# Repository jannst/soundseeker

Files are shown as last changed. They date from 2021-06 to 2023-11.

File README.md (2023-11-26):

# Soundseeker
The Soundseeker project originated from my need to measure the speed of sound traveling through wood, a crucial characteristic in selecting wood for musical instrument making. Regrettably, there was no affordable method available, prompting me to embark on building a device capable of measuring this parameter independently. The project commenced in 2017 with the development of the initial prototype. Throughout the process, I gained valuable insights, and I am currently at the third prototype stage, incorporating a custom PCB, surface-mount device (SMD) parts and even a step-up DC-DC converter to drive the piezo acuator.

This Repository contains only the source code for the third prototype.

## Prototype I (2017)
<div style="display: flex">
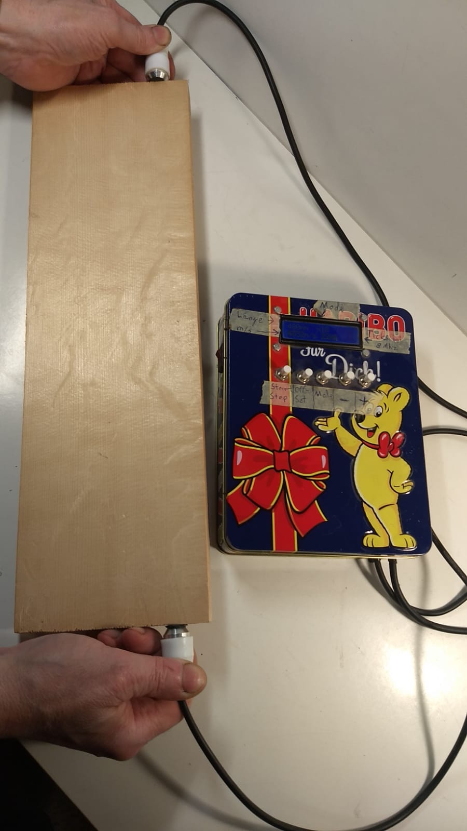
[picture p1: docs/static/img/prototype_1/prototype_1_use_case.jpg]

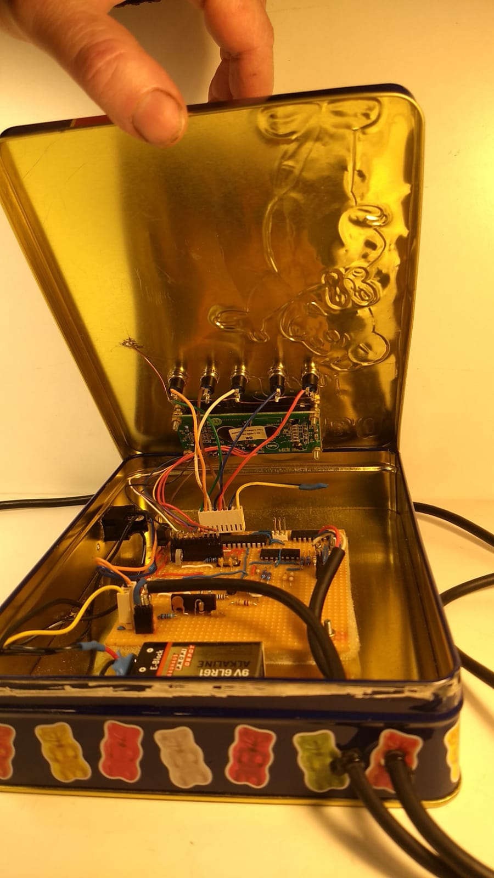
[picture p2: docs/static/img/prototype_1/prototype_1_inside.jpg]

</div>
The first prototype used an ATMEAGA-8 as MCU and a Haribo sweets box as enclosure. 

## Prototype II (2020)
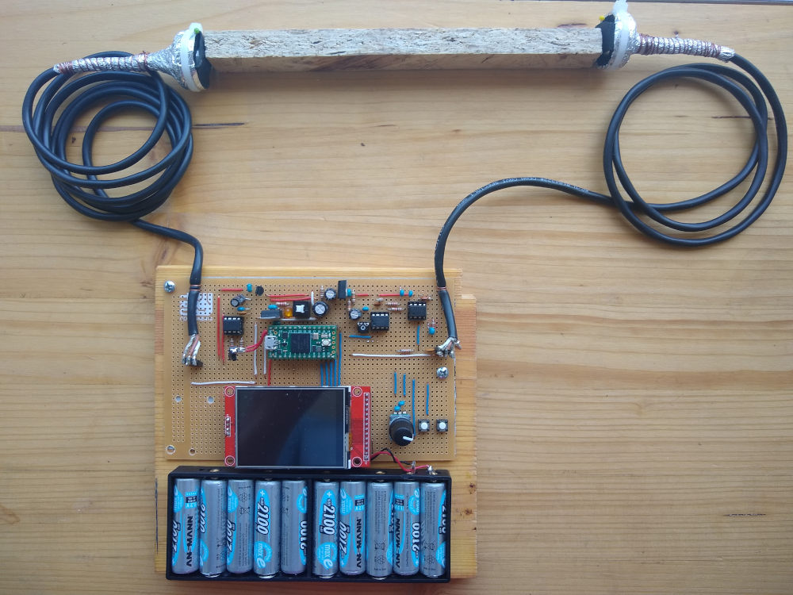
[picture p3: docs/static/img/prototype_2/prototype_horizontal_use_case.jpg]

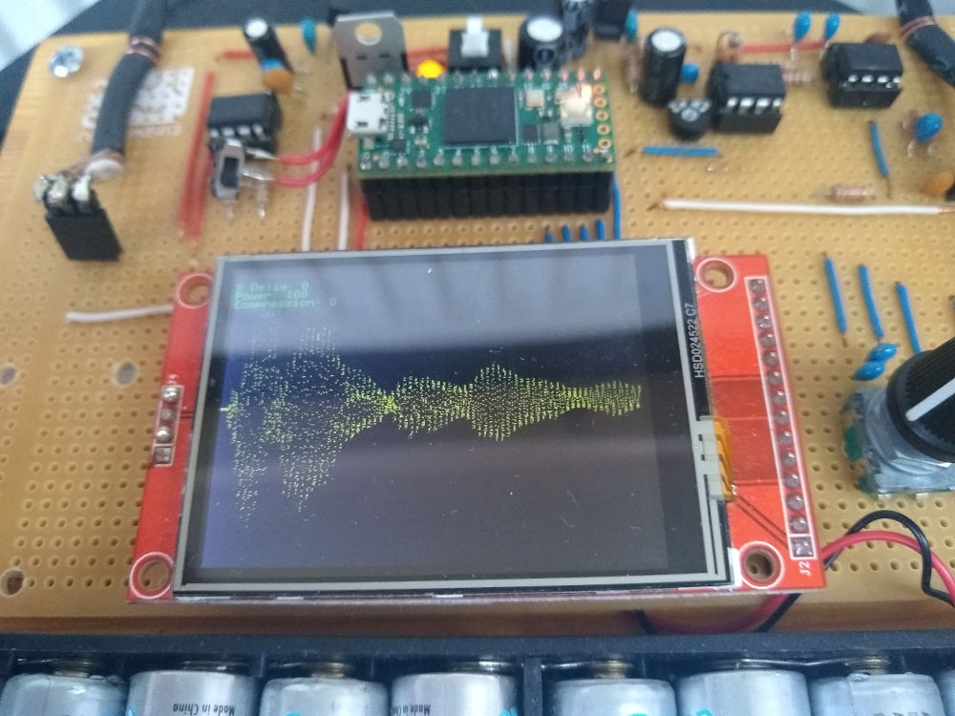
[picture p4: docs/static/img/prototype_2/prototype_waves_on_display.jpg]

The second prototype uses a very powerful Teensy 4 board and utilises a display which even allows to visualise the waveform.

## Prototype III (2022)
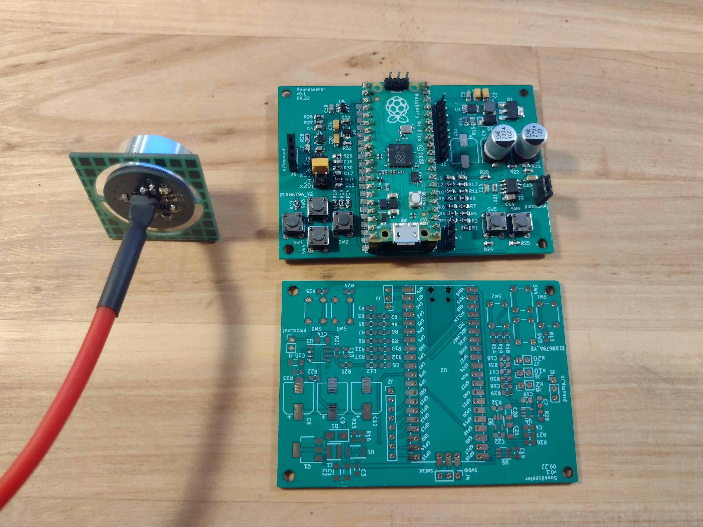
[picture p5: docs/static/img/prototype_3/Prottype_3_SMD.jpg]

The third prototype features custom PCBs and utilizes the RP2040 microcontroller, providing USB connectivity. The display was omitted to enable visualization of transmitted data through laptops or mobile phones connected via USB. The pre-amplifier for the piezo sensor is situated on the PCB to which the sensor is soldered, ensuring a very short, high-impedance signal path.

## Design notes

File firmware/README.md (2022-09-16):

# Soundseeker Firmware

## Project Setup
  - Download RPI Pico SDK and setup `PICO_SDK_PATH` env variable on your system
  - Open Project in VS Code
  - Setup a [picoprobe](https://github.com/raspberrypi/picoprobe) for firmware flashing and debugging
  - Have a look at the scripts inside the bin folder
  - When using serial remember how to leave minicom: CTRL+A, then press X

### Debugging
  Checkout [this Digikey article](https://www.digikey.de/de/maker/projects/raspberry-pi-pico-and-rp2040-cc-part-2-debugging-with-vs-code/470abc7efb07432b82c95f6f67f184c0) on how to debug RP2040 with VS Code

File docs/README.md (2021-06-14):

# Ultrasonic Sound Tester Abstract an logbook site
Uses [Pico](https://github.com/negrel/hugo-theme-pico/) theme

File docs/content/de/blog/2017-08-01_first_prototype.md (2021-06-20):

+++
title = "Der erste Prototyp"
subtitle = ""
date = 2017-08-01

description = "Kurze Beschreibung des ersten Prototypen mit Erläuterung der Arbeitsweise"
banner = ''

[[pic]]
  url = "/img/prototype_1/prototype_1.jpg"
  label = "Gesamtansicht"
  height = "250px"

[[pic]]
  url = "/img/prototype_1/prototype_1_inside.jpg"
  label = "Innenansicht"
  height = "250px"
[[pic]]
  url = "/img/prototype_1/prototype_1_use_case.jpg"
  label = "Messung der Schallgeschwindigkeit in Cello Deckenholz"
  height = "250px"
[[pic]]
  url = "/img/prototype_1/prototype_1_horizontal.jpg"
  label = "Gesamtansicht"
  height = "250px"
+++

Der erste Prototyp ist ein Nachbau, des [Luccimeters](https://www.lucchimeter.com/), welches zur Zeit 
bei F.W. Geigenbu in Bremen im Einsatz ist. Dort  wird es zur Vermessung von Bogen- und Geigenholz genutzt. 

Es verfügt über 2 40kHz Piezo-Elemente, welche den Ultraschall in das Material einbringen und wieder abnehmen. Das Signal wird dann verstärkt und
durch einen Atmega-8 Microcontroller wird ausgewertet, wie lang der Schall benötigt hat um das Material zu durchqueren.
Zusammen mit der eingegebenen Länge wird die Schallgeschwindigkeit im Material gemessen.

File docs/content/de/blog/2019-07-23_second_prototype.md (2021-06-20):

+++
title = "Der zweite Prototyp"
subtitle = ""
date = 2019-07-23

description = "Aufbau und Funktionsweise des zweiten Prototypes"
banner = ''
[[pic]]
  url = "/img/prototype_2/prototype_vertical.jpg"
  label = "Gesamtansicht"
  height = "250px"
[[pic]]
  url = "/img/prototype_2/prototype_backside.jpg"
  label = "Rückseite der Platine"
  height = "250px"
[[pic]]
  url = "/img/prototype_2/prototype_horizontal_use_case.jpg"
  label = "Möglicher Anwendungsfall"
  height = "250px"
[[pic]]
  url = "/img/prototype_2/prototype_waves_on_display.jpg"
  label = "Anzeige der Rohdaten auf dem Display"
  height = "250px"
+++

Der zweite Prototyp arbeitet mit dem selben Piezo-Wandlern, allerdings wurden die Schaltungen für 
die Signalerzeugung und -verstärkung mit Hile von Thomas XXXX, einem pensionierten Elektrotechnisker überarbeitet. 
Es wurde ebenfalls ein Bildschirm und ein leistungsstarker Teensy 4.0 Microcontroller verbaut.
Da dieser über einen 1MSP/S ADC verfügt, können die 40kHz Schallwellen nun abgenommen und digital verarbeitet werden.

Der Prototyp ist in der Lage Schallwellen von 40kHz zu erzeugen, in das Material einzubringen, dann wieder abzunehmen, analog zu verstärken und anschließend auf einem kleinen Display anzuzeigen.

Es fehlt aber noch ein vernünftiges Bewertungsverfahren, welches die abegommenen Schallwellen auswertet. Dabei muss berücksichtigt werden, dass die die Piezos mit der Hand an das Werkstück gehalten werden und die Ergebnisse somit je nach Anpressdruck und -winkel mitunter stark variieren. Gleichzeitig sind die verwendeten Piezos vermutlich nicht die optimale Wahl für die beschriebene Anwendung, es konnten allerdings keine
passenderen Elemente mit dem zur Verfügung stehenden Budget organisiert werden. Es stellt sich außerdem die Frage ob sich 40kHz als Frequenz zur Durschschallung von Feststoffen eignet.
Außerdem muss ein Weg gefunden Werten, einen Piezo Treiber zu betreiben, der möglichst Hohe Spannungsamplitunden liefern, gleichzeitig aber mit einem 5V Akku bereiben werden kann,

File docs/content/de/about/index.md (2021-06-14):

+++
title = "Über das Projekt"

type = "blog"
+++

## Problemstellung
Beim Bau eines Holzmusikinstrumentes muss Holz ausgewählt werden, welches Materialeigenschaften besitzt, die sich positiv auf die akustische Qualität auswirken.
Im Holzhandel müssen somit aus einer Vielzahl von verschiedenen Stücken, einige passende ausgewählt werden.
Um die besten Stücke identifizieren zu können, haben sich über die Jahre verschiedene Heuristiken entwickelt. Relativ bekannt sind verschiedene
"Klopftests", bei denen ein Stück Holz z.B. zwischen zwei Fingern an einem Schwingungsknoten einer Eigenmode gehalten 
und mit der Hand "angeklopft" wird. Der vom Holz abgestrahlte Klang wird dann anhand der eigenen Erfahrung subjektiv bewertet.
Das "geschulte Ohr" ist dann in der Lage, eine Bewertung über die Eignung des Holzes für den Instrumentenbau zu liefern.

Auch bei der Ausarbeitung des Materials ist es wichtig, darauf zu achten, dass später ein akustisch gut klingendes Instrument entsteht. 
So ist bei Gitarren und Streichinstrumenten die Ausarbeitung der Materialstärken der Decke und deren Bebalkung von essenzieller Bedeutung. https://www.thisisclassicalguitar.com/bracing-styles-for-classical-guitars/
Das Werkstück wird dabei immer wieder auf die Merkmale geprüft, welche später die akustische Qualität beeinflussen.
Es wird zum Beispiel mit den Händen geprüft, wie biegsam das Werkstück ist oder wie sich der Klang beim Klopfen an einer bestimmten Stelle anhört.

Es ist offensichtlich, dass in der Bewertung und Bearbeitung von Holz, die subjektive Erfahrung eine große Rolle spielt.
Währenddessen wird in der Werkstofftechnik seit längerem mit Ultraschall gearbeitet, um Werkstoffe auf Fehler zu prüfen oder Materialeigenschaften bestimmen zu können.
Es soll der Versuch unternommen werden, Verfahren aus dieser Domäne im Instrumentenbau anzuwenden.

## Das Luccimeter
Es gibt bereits ein Gerät, welches Ulraschallimpulse in ein Stück Holz einbringt und diese dann wieder abnimmt.
Zusammen mit der eigegebenen Länge des Holzstückes kann dann die Schallgeschwindigkeit im Material bestimmt werden.
Es findet aktuell hauptsächlich in der Bewertung von Bogenholz, aber auch in der Auswahl und Ausarbeitung von Geigen- und Gitarrenholz Verwendung.
Das Gerät ist in der Lage, die Schallgeschwindigkeit im Material zu messen, kann aber über die wieder aufgenommenen Schallwellen keine weiteren Aussagen treffen. 
(see https://www.lucchimeter.com/)

## Zielsetzung
Ziel des Projektes ist es, ein Gerät zu entwickeln, welches mit Hilfe von Ultraschall Materialeigenschaften des Holzes bestimmen und damit die oben beschriebenen
Techniken unterstützen und gegebenfalls eine Grundlage zur Bewertung von Holz darstellen kann.
Dabei ist es wichtig, dass Messungen einfach und schnell durchgeführt werden können und
das Gerät dabei portabel und gleichzeitg kostengünstig ist. 
Die Messergebnisse sollten möglichst einfach auszuwerten sein, am Besten mittels errechneten "Scores" für verschiedene Eigenschaften.
Dabei sind absolute Werte weniger von Interesse als die Möglichkeit verschiedene Holzstücke miteinander zu vergleichen und Verhältnisse zwischen Messpunkten bestimmen zu können.
Das Gerät soll ähnlich wie das oben beschriebene Luccimeter funktionieren, allerdings über die Messung der Schallgeschwindigkeit hinaus, auch die abegenommenen Wellen weiter analysieren.
Es sollen idealerweise Aussagen über die Dämpfung und die Elastizität des Materials getroffen werden.

## Bisherige Arbeit
Bisher wurden 2 Prototypen gebaut. Der ersten Prototyp ist ein Nachbau, des oben beschriebenen Luccimeter, welches zur Zeit 
bei F.W. Geigenbu in Bremen im Einsatz ist und dort zur Vermessung von Bogen- und Geigenholz genutzt wird. 
Es verfügt über 2 40kHz Piezo-Elemente, welche den Ultraschall in das Material einbringen und wieder abnehmen.
Ein Atmega-8 Microcontroller wertet dann aus, wie lang der Schall benötigt hat um das Material zu durchqueren.
Zusammen mit der eingegebenen Länge wird die Schallgeschwindigkeit im Material gemessen. 

Der zweite Prototyp arbeitet mit dem selben Piezo-Wandlern, allerdings wurden die Schaltungen für 
die Signalerzeugung und -verstärkung mit Hile von Thomas XXXX, einem pensionierten Elektrotechnisker überarbeitet. 
Es wurde ebenfalls ein Bildschirm und ein leistungsstarker Teensy 4.0 Microcontroller verbaut.
Da dieser über einen 1MSP/S ADC verfügt, können die 40kHz Schallwellen nun abgenommen und digital verarbeitet werden.

Der Prototyp ist in der Lage Schallwellen von 40kHz zu erzeugen, in das Material einzubringen, dann wieder abzunehmen, analog zu verstärken und anschließend auf einem kleinen Display anzuzeigen.

Es fehlt aber noch ein vernünftiges Bewertungsverfahren, welches die abgenommenen Schallwellen auswertet. Dabei muss berücksichtigt werden, dass die Piezos mit der Hand an das Werkstück gehalten werden und die Ergebnisse somit je nach Anpressdruck und -winkel mitunter stark variieren. Gleichzeitig sind die verwendeten Piezos vermutlich nicht die optimale Wahl für die beschriebene Anwendung, es konnten allerdings keine
passenderen Elemente mit dem zur Verfügung stehenden Budget organisiert werden. Es stellt sich außerdem die Frage ob sich 40kHz als Frequenz zur Durschschallung von Feststoffen eignet.
Außerdem muss ein Weg gefunden Werten, einen Piezo Treiber zu betreiben, der möglichst hohe Spannungsamplitunden liefern, gleichzeitig aber mit einem 5V Akku betrieben werden kann,

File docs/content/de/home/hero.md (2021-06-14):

+++
widget = "hero"
weight = 10

hero_media = "/img/prototype_2/prototype_vertical.jpg"

[[btn]]
  url = "/about"
  label = "Mehr Erfahren"
	primary = true
+++

# **Projekt Soundseeker**
Mit dem Soundseeker soll der Versuch unternommen werden, ein Messgerät zu bauen, welches mithilfe von nicht destruktiven Ultraschall Prüfverfahren,
Materialeigenschaften von Holz bestimmen kann. Es soll bei der Materialauswahl des Holzes und im Herstellungsprozess unterstützen, um letztlich klanglich bessere Instrumente bauen und den Werkstoff Holz besser verstehen zu können.

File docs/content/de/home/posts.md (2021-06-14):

+++

widget = "pages"
weight = 50 

title = "Logbuch"
subtitle = "Entwicklungsverlauf des Projektes für Interessierte"

[content]
	page_type = "blog"
+++

:disappointed: There are no posts at the moment. :disappointed:

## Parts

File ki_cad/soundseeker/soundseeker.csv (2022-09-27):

Source: | /home/metro/git/soundseeker/ki_cad/soundseeker/soundseeker.kicad_sch
Date: | Sa 17 Sep 2022 15:48:06 CEST
Tool: | Eeschema 6.0.7-f9a2dced07~116~ubuntu20.04.1
Generator: | /usr/share/kicad/plugins/bom_csv_grouped_by_value.py
Component Count: | 46
Individual Components:
Item | Qty | Reference(s) | Value | LibPart | Footprint | Datasheet | Description | Type
 |  | C1 | 10u | Device:C | Resistor_SMD:R_1206_3216Metric_Pad1.30x1.75mm_HandSolder | ~ | Tantal 10V 10%
 |  | C2 | 10u | Device:C | Resistor_SMD:R_1206_3216Metric_Pad1.30x1.75mm_HandSolder | ~ | Tantal 10V 10%
 |  | C3 | 1u | Device:C | Resistor_SMD:R_0805_2012Metric_Pad1.20x1.40mm_HandSolder | ~ | 16V X7R 10%
 |  | C4 | 10u | Device:C | Resistor_SMD:R_1206_3216Metric_Pad1.30x1.75mm_HandSolder | ~ | Tantal 10V 10%
 |  | C5 | 1n | Device:C | Capacitor_SMD:C_0805_2012Metric_Pad1.18x1.45mm_HandSolder | ~ | 10% 50V
 |  | C6 | 1u | Device:C | Capacitor_SMD:C_1206_3216Metric_Pad1.33x1.80mm_HandSolder | ~ | 10% 100V X7R
 |  | C7 | 10n | Device:C | Resistor_SMD:R_0805_2012Metric_Pad1.20x1.40mm_HandSolder | ~ | 10% 50V X7R
 |  | C8 | 22u | Device:C_Polarized | Capacitor_SMD:CP_Elec_8x10.5 | https://www.mouser.de/datasheet/2/40/kyocera_avx_aea_series-2526131.pdf | 100V | AEA0810220M100R
 |  | C9 | 22u | Device:C_Polarized | Capacitor_SMD:CP_Elec_8x10.5 | https://www.mouser.de/datasheet/2/40/kyocera_avx_aea_series-2526131.pdf | 100V | AEA0810220M100R
 |  | C10 | 470p | Device:C | Resistor_SMD:R_0805_2012Metric_Pad1.20x1.40mm_HandSolder | ~ | 5% 100V C0G
 |  | C11 | 22u | Device:C_Polarized | Capacitor_SMD:CP_Elec_8x10.5 | https://www.mouser.de/datasheet/2/40/kyocera_avx_aea_series-2526131.pdf | 100V | AEA0810220M100R
 |  | C12 | 10n | Device:C | Resistor_SMD:R_0805_2012Metric_Pad1.20x1.40mm_HandSolder | ~ | 10% 50V X7R
 |  | C13 | 15p | Device:C | Resistor_SMD:R_0805_2012Metric_Pad1.20x1.40mm_HandSolder | ~ | 5% 50V
 |  | C14 | 1u | Device:C | Capacitor_SMD:C_1206_3216Metric_Pad1.33x1.80mm_HandSolder | ~ | 10% 100V X7R
 |  | C15 | 1u | Device:C | Capacitor_SMD:C_1206_3216Metric_Pad1.33x1.80mm_HandSolder | ~ | 10% 100V X7R
 |  | C16 | 1u | Device:C | Resistor_SMD:R_0805_2012Metric_Pad1.20x1.40mm_HandSolder | ~ | 16V X7R 10%
 |  | D1 | RB058L150DDTE25 | Device:D_Schottky | Diode_SMD:D_SOD-128 | https://fscdn.rohm.com/en/products/databook/datasheet/discrete/diode/schottky_barrier/rb058l150ddte25-e.pdf
 |  | J1 | Conn_01x11 | Connector_Generic:Conn_01x11 | Connector_PinHeader_2.54mm:PinHeader_1x11_P2.54mm_Vertical | ~
 |  | L1 | 2.2u | Device:L | Inductor_SMD:L_Vishay_IFSC-1515AH_4x4x1.8mm | https://www.mouser.de/datasheet/2/427/sc15ah01-1762292.pdf |  | IFSC1515AHER2R2M01
 |  | Q1 | FDT86113LZ | soundseeker:FDT86113LZ | Package_TO_SOT_SMD:SOT-223-3_TabPin2 | https://www.mouser.de/datasheet/2/308/1/FDT86113LZ_D-1809132.pdf
 |  | R1 | 2k | Device:R | Resistor_SMD:R_0805_2012Metric_Pad1.20x1.40mm_HandSolder | ~ | 250mW 1%
 |  | R2 | 2k | Device:R | Resistor_SMD:R_0805_2012Metric_Pad1.20x1.40mm_HandSolder | ~ | 250mW 1%
 |  | R3 | 1k | Device:R | Resistor_SMD:R_0805_2012Metric_Pad1.20x1.40mm_HandSolder | ~ | 250mW 1%
 |  | R4 | 2k | Device:R | Resistor_SMD:R_0805_2012Metric_Pad1.20x1.40mm_HandSolder | ~ | 250mW 1%
 |  | R5 | 1k | Device:R | Resistor_SMD:R_0805_2012Metric_Pad1.20x1.40mm_HandSolder | ~ | 250mW 1%
 |  | R6 | 2k | Device:R | Resistor_SMD:R_0805_2012Metric_Pad1.20x1.40mm_HandSolder | ~ | 250mW 1%
 |  | R7 | 1k | Device:R | Resistor_SMD:R_0805_2012Metric_Pad1.20x1.40mm_HandSolder | ~ | 250mW 1%
 |  | R8 | 2k | Device:R | Resistor_SMD:R_0805_2012Metric_Pad1.20x1.40mm_HandSolder | ~ | 250mW 1%
 |  | R9 | 1k | Device:R | Resistor_SMD:R_0805_2012Metric_Pad1.20x1.40mm_HandSolder | ~ | 250mW 1%
 |  | R10 | 2k | Device:R | Resistor_SMD:R_0805_2012Metric_Pad1.20x1.40mm_HandSolder | ~ | 250mW 1%
 |  | R11 | 1k | Device:R | Resistor_SMD:R_0805_2012Metric_Pad1.20x1.40mm_HandSolder | ~ | 250mW 1%
 |  | R12 | 2k | Device:R | Resistor_SMD:R_0805_2012Metric_Pad1.20x1.40mm_HandSolder | ~ | 250mW 1%
 |  | R13 | 20k | Device:R | Resistor_SMD:R_0805_2012Metric_Pad1.20x1.40mm_HandSolder | ~ | 250mW 1%
 |  | R14 | 20k | Device:R | Resistor_SMD:R_0805_2012Metric_Pad1.20x1.40mm_HandSolder | ~ | 250mW 1%
 |  | R15 | 100k | Device:R | Resistor_SMD:R_0805_2012Metric_Pad1.20x1.40mm_HandSolder | ~ | 250mW 1%
 |  | R16 | 1.69k | Device:R | Resistor_SMD:R_0805_2012Metric_Pad1.20x1.40mm_HandSolder | ~ | 125mW 1%
 |  | R17 | 100 | Device:R | Resistor_SMD:R_0805_2012Metric_Pad1.20x1.40mm_HandSolder | ~ | 250mW 1%
 |  | R18 | 1k | Device:R | Resistor_SMD:R_0805_2012Metric_Pad1.20x1.40mm_HandSolder | ~ | 250mW 1%
 |  | R19 | 2.2k | Device:R | Resistor_SMD:R_0805_2012Metric_Pad1.20x1.40mm_HandSolder | ~ | 250mW 1%
 |  | R20 | 2.2k | Device:R | Resistor_SMD:R_0805_2012Metric_Pad1.20x1.40mm_HandSolder | ~ | 250mW 1%
 |  | R21 | 47k | Device:R | Resistor_SMD:R_0805_2012Metric_Pad1.20x1.40mm_HandSolder | ~ | 250mW 1%
 |  | R22 | 20k | Device:R | Resistor_SMD:R_0805_2012Metric_Pad1.20x1.40mm_HandSolder | ~ | 250mW 1%
 |  | R23 | 20k | Device:R | Resistor_SMD:R_0805_2012Metric_Pad1.20x1.40mm_HandSolder | ~ | 250mW 1%
 |  | U1 | MCP1652 | Regulator_Switching:MCP1652 | Package_SO:MSOP-8_3x3mm_P0.65mm | http://ww1.microchip.com/downloads/en/DeviceDoc/21876B.pdf
 |  | U2 | TLV9052S | soundseeker:TLV9052S | Package_SO:MSOP-10_3x3mm_P0.5mm | https://www.ti.com/lit/ds/symlink/tlv9052.pdf
 |  | U3 | OPA453 | soundseeker:OPA453 | Package_TO_SOT_SMD:TO-263-7_TabPin4 | https://www.ti.com/lit/ds/symlink/opa453.pdf
Collated Components:
Item | Qty | Reference(s) | Value | LibPart | Footprint | Datasheet | Description | Type
1 | 3 | C1, C2, C4 | 10u | Device:C | Resistor_SMD:R_1206_3216Metric_Pad1.30x1.75mm_HandSolder | ~ | Tantal 10V 10%
2 | 2 | C3, C16 | 1u | Device:C | Resistor_SMD:R_0805_2012Metric_Pad1.20x1.40mm_HandSolder | ~ | 16V X7R 10%
3 | 1 | C5 | 1n | Device:C | Capacitor_SMD:C_0805_2012Metric_Pad1.18x1.45mm_HandSolder | ~ | 10% 50V
4 | 3 | C6, C14, C15 | 1u | Device:C | Capacitor_SMD:C_1206_3216Metric_Pad1.33x1.80mm_HandSolder | ~ | 10% 100V X7R
5 | 2 | C7, C12 | 10n | Device:C | Resistor_SMD:R_0805_2012Metric_Pad1.20x1.40mm_HandSolder | ~ | 10% 50V X7R
6 | 3 | C8, C9, C11 | 22u | Device:C_Polarized | Capacitor_SMD:CP_Elec_8x10.5 | https://www.mouser.de/datasheet/2/40/kyocera_avx_aea_series-2526131.pdf | 100V | AEA0810220M100R
7 | 1 | C10 | 470p | Device:C | Resistor_SMD:R_0805_2012Metric_Pad1.20x1.40mm_HandSolder | ~ | 5% 100V C0G
8 | 1 | C13 | 15p | Device:C | Resistor_SMD:R_0805_2012Metric_Pad1.20x1.40mm_HandSolder | ~ | 5% 50V
9 | 1 | D1 | RB058L150DDTE25 | Device:D_Schottky | Diode_SMD:D_SOD-128 | https://fscdn.rohm.com/en/products/databook/datasheet/discrete/diode/schottky_barrier/rb058l150ddte25-e.pdf
10 | 1 | J1 | Conn_01x11 | Connector_Generic:Conn_01x11 | Connector_PinHeader_2.54mm:PinHeader_1x11_P2.54mm_Vertical | ~
11 | 1 | L1 | 2.2u | Device:L | Inductor_SMD:L_Vishay_IFSC-1515AH_4x4x1.8mm | https://www.mouser.de/datasheet/2/427/sc15ah01-1762292.pdf |  | IFSC1515AHER2R2M01
12 | 1 | Q1 | FDT86113LZ | soundseeker:FDT86113LZ | Package_TO_SOT_SMD:SOT-223-3_TabPin2 | https://www.mouser.de/datasheet/2/308/1/FDT86113LZ_D-1809132.pdf
13 | 7 | R1, R2, R4, R6, R8, R10, R12 | 2k | Device:R | Resistor_SMD:R_0805_2012Metric_Pad1.20x1.40mm_HandSolder | ~ | 250mW 1%
14 | 6 | R3, R5, R7, R9, R11, R18 | 1k | Device:R | Resistor_SMD:R_0805_2012Metric_Pad1.20x1.40mm_HandSolder | ~ | 250mW 1%
15 | 4 | R13, R14, R22, R23 | 20k | Device:R | Resistor_SMD:R_0805_2012Metric_Pad1.20x1.40mm_HandSolder | ~ | 250mW 1%
16 | 1 | R15 | 100k | Device:R | Resistor_SMD:R_0805_2012Metric_Pad1.20x1.40mm_HandSolder | ~ | 250mW 1%
17 | 1 | R16 | 1.69k | Device:R | Resistor_SMD:R_0805_2012Metric_Pad1.20x1.40mm_HandSolder | ~ | 125mW 1%
18 | 1 | R17 | 100 | Device:R | Resistor_SMD:R_0805_2012Metric_Pad1.20x1.40mm_HandSolder | ~ | 250mW 1%
19 | 2 | R19, R20 | 2.2k | Device:R | Resistor_SMD:R_0805_2012Metric_Pad1.20x1.40mm_HandSolder | ~ | 250mW 1%
20 | 1 | R21 | 47k | Device:R | Resistor_SMD:R_0805_2012Metric_Pad1.20x1.40mm_HandSolder | ~ | 250mW 1%
21 | 1 | U1 | MCP1652 | Regulator_Switching:MCP1652 | Package_SO:MSOP-8_3x3mm_P0.65mm | http://ww1.microchip.com/downloads/en/DeviceDoc/21876B.pdf
22 | 1 | U2 | TLV9052S | soundseeker:TLV9052S | Package_SO:MSOP-10_3x3mm_P0.5mm | https://www.ti.com/lit/ds/symlink/tlv9052.pdf
23 | 1 | U3 | OPA453 | soundseeker:OPA453 | Package_TO_SOT_SMD:TO-263-7_TabPin4 | https://www.ti.com/lit/ds/symlink/opa453.pdf

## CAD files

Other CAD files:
ki_cad/KiCad-RP-Pico/SketchUp Model/Pico.skp

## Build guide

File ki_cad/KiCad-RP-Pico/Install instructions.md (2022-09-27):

# Install instructions

## 1. Copy the files locally

Copy the `RP-Pico Libraries` folder wherever you like on your computer.

## 2. Install the Raspberry Pi Pico board schema symbol

Use the `KiCad | Preferences | Manage Symbol Libraries...` command to manage the symbol library:



then select the global tab and click on the folder button:



navigate to the `RP-Pico Libraries` folder, select the `MCU_RaspberryPi_and_Boards.kicad_sym` file and open it:



et voilà, the first step is completed:



You can now close the symbol libraries manager window.

## 3. Install the Raspberry Pi Pico board footprint

You can use a similar approach to add the footprint to the footprint libraries manager, but I've found some issues that I've solved using the footprint editor, so here are the steps I suggest you to follow:

Open the footprint editor



wait for the footprints to load... then use the `File | Add Library` command:



confirm the `Global` choice:



and select the `MCU_RaspberriPi_and_Boards.pretty` folder (yes, the folder represent a footprint library on KiCad):



Now the library is installed on KiCad with the Raspberry Pi Pico footprint (double click on it to see it on the editor pane):



Don't close the windows as the next step start from here.

## 4. Install the Raspberry Pi Pico board footprint 3D visual

If not already open, open the the footprint editor

symbol library manager

double click on the `RPi_Pico_SMD_TH` footprint from the `MCU_RaspberriPi_and_Boards` library and then click on the `Footprint properties` icon:



In the footprint properties window, first select the `3D Settings` tab. Please note that the preview shows only the PCB board with the footprint added on step 3, without any 3D representation of the Raspberry Pi Pico board. Now click on the folder icon to add the 3D model:



Navigate to the `RP-Pico Libraries` folder, select the `Pico.wrl` file and wait until the model is shown in the right panel, then confirm with OK:



The model is already scaled and translated to match the footprint:



now close the `Footprint Properties` window, and the `Footprint Editor`, obviously saving the changes.

## Conclusion

Now that you've installed the schema and footprint and added the 3D model to the footprint, you can use the Raspberry Pi Pico board on your KiCad projects.

I've also added a test KiCad Project on the `Test` folder, that you can use to see an example of it.

Have fun!

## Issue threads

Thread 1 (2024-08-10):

Technical and Hardware Information

rasooliranpoor, 2024-08-10:
Hello,
I also need a device similar to the Lucchi meter for an experimental project, and I was very pleased to see your work. However, I have an issue with the receiving sensors. What is the operating frequency of the piezoelectrics? Is the frequency the same 40kHz as shown in the schematic?
Could you share more detailed electronic information? I want to use this project entirely from scratch with STM, and I need more precise information to ensure fewer errors at the start.

jannst, 2024-09-22:
Hey, sorry for the late answer. Yes the used piezos are 40khz. It was really difficult to find affordable Sensors on Mouser/Digikey so I ended up sourcing them from AliExpress. When I was experimenting with them I encountered a signifikant amount of ringing so it was not possible for me to implement Pulse Echo measurements with a single pizeo. Also a big learning for me was to put the preamplifier as close as possible to the piezo as it probably reduced parasitic capacitance of the wire. If you have more specific questions feel free to reach out.

rasooliranpoor, 2024-10-10:
Hello

Thank you very much for your response.

 I couldn’t find a 40 kHz piezo in the market, so I think I should use a 38
kHz cold mist device instead. However, I found some high-frequency piezos
in the MHz range, but there isn’t detailed technical information available.
Ordering from outside Iran is also a bit difficult for me. Additionally,
op-amps and other components are not available in our current market, so I
need to use suitable alternatives from the available op-amps. Another issue
is the MCP1652, which seems to be used for driving the piezo. Can I use a
MOSFET transistor with higher voltage for switching the higher voltage
piezo instead?

Once again, thank you for the time you took to respond.

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

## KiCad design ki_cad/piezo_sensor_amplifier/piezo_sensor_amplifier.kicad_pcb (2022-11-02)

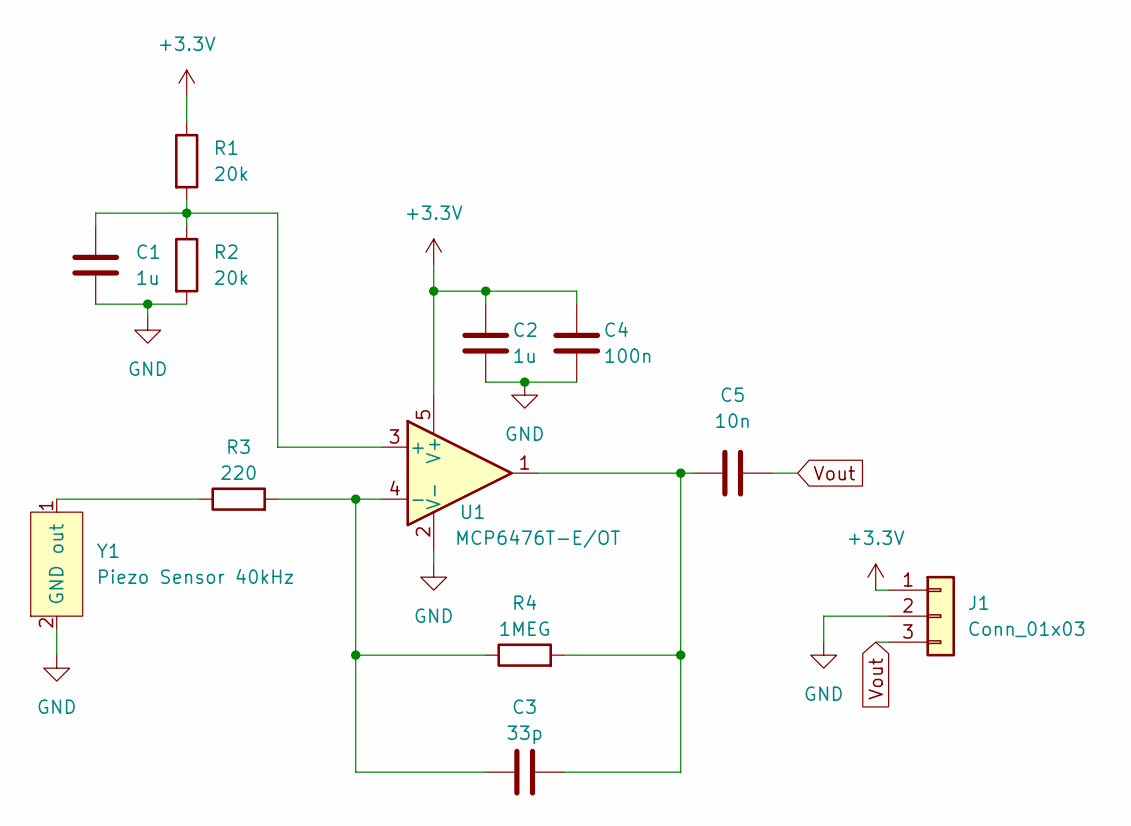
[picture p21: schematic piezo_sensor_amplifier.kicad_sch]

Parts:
C1, C2: 1u; R_0805_2012Metric_Pad1.20x1.40mm_HandSolder
C3: 33p; C_0805_2012Metric_Pad1.18x1.45mm_HandSolder
C4: 100n; C_0805_2012Metric_Pad1.18x1.45mm_HandSolder
C5: 10n; C_0805_2012Metric_Pad1.18x1.45mm_HandSolder
J1: Conn_01x03; PinHeader_1x03_P2.54mm_Vertical
R1, R2: 20k; R_0805_2012Metric_Pad1.20x1.40mm_HandSolder
R3: 220; R_0805_2012Metric_Pad1.20x1.40mm_HandSolder
R4: 1MEG; R_0805_2012Metric_Pad1.20x1.40mm_HandSolder
U1: MCP6476T-E/OT; SOT-23-5
Y1: Piezo Sensor 40kHz; piezo_sensor_D25mm

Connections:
+3.3V: C2.1, C4.1, J1.1, R1.1, U1.5 (V+)
GND: C1.2, C2.2, C4.2, J1.2, R2.2, U1.2 (V-), Y1.2 (GND)
unnamed: C1.1, R1.2, R2.1, U1.3 (+)
unnamed: C3.1, R3.2, R4.1, U1.4 (-)
unnamed: C3.2, C5.1, R4.2, U1.1
unnamed: R3.1, Y1.1 (out)
Vout: C5.2, J1.3

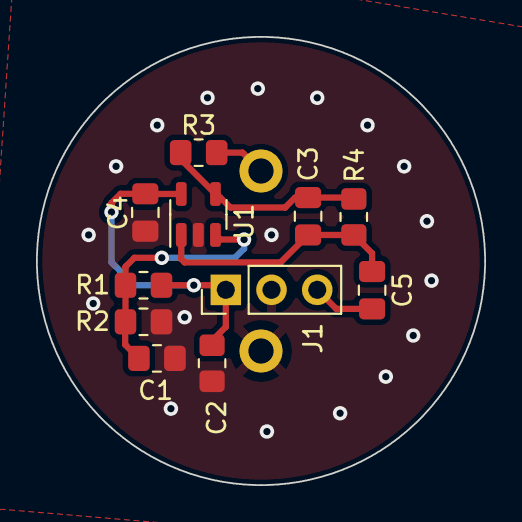
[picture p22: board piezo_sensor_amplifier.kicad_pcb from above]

Board: 2 copper layers, 24.9 x 24.9 mm, 12 parts (0 on the bottom side), 7 nets.

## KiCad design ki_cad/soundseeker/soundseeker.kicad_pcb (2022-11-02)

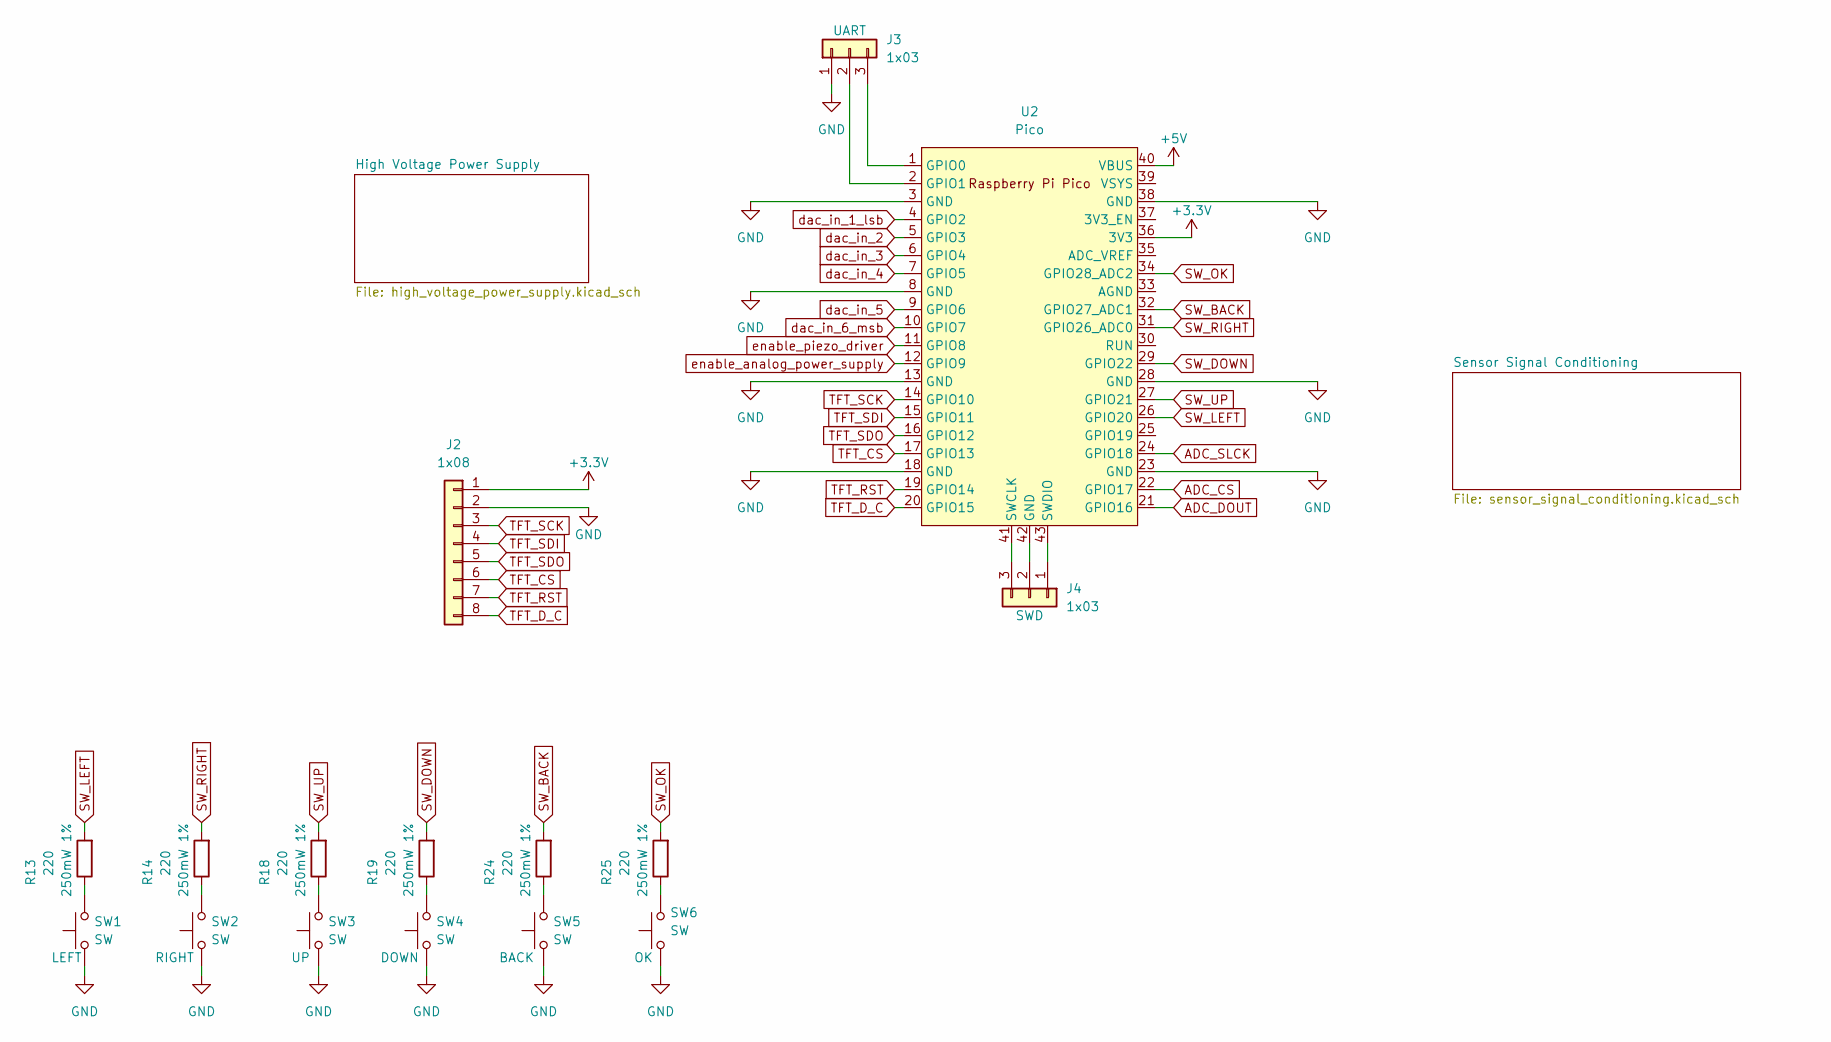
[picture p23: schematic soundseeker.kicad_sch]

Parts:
J2: 1x08; PinHeader_1x08_P2.54mm_Vertical
J3, J4: 1x03; PinHeader_1x03_P2.54mm_Vertical
R13, R14, R18, R19, R24, R25: 220; R_0805_2012Metric_Pad1.20x1.40mm_HandSolder
SW1, SW2, SW3, SW4, SW5, SW6: SW; SW_PUSH_6mm
U2: Pico; RPi_Pico_SMD_TH

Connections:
+3.3V: J2.1, U2.36 (3V3)
+5V: U2.40 (VBUS); also elsewhere on the board
ADC_CS: U2.22 (GPIO17); also elsewhere on the board
ADC_DOUT: U2.21 (GPIO16); also elsewhere on the board
ADC_SLCK: U2.24 (GPIO18); also elsewhere on the board
GND: J2.2, J3.1, SW1.1, SW2.1, SW3.1, SW4.1, SW5.1, SW6.1, U2.3 (GND), U2.8 (GND), U2.13 (GND), U2.18 (GND), U2.23 (GND), U2.28 (GND), U2.38 (GND); also elsewhere on the board
unnamed: J3.2, U2.2 (GPIO1)
unnamed: J3.3, U2.1 (GPIO0)
unnamed: J4.1, U2.43 (SWDIO)
unnamed: J4.2, U2.42 (GND)
unnamed: J4.3, U2.41 (SWCLK)
unnamed: R13.1, SW1.2
unnamed: R14.1, SW2.2
unnamed: R18.1, SW3.2
unnamed: R19.1, SW4.2
unnamed: R24.1, SW5.2
unnamed: R25.1, SW6.2
SW_BACK: R24.2, U2.32 (GPIO27_ADC1)
SW_DOWN: R19.2, U2.29 (GPIO22)
SW_LEFT: R13.2, U2.26 (GPIO20)
SW_OK: R25.2, U2.34 (GPIO28_ADC2)
SW_RIGHT: R14.2, U2.31 (GPIO26_ADC0)
SW_UP: R18.2, U2.27 (GPIO21)
TFT_CS: J2.6, U2.17 (GPIO13)
TFT_D_C: J2.8, U2.20 (GPIO15)
TFT_RST: J2.7, U2.19 (GPIO14)
TFT_SCK: J2.3, U2.14 (GPIO10)
TFT_SDI: J2.4, U2.15 (GPIO11)
TFT_SDO: J2.5, U2.16 (GPIO12)
dac_in_1_lsb: U2.4 (GPIO2); also elsewhere on the board
dac_in_2: U2.5 (GPIO3); also elsewhere on the board
dac_in_3: U2.6 (GPIO4); also elsewhere on the board
dac_in_4: U2.7 (GPIO5); also elsewhere on the board
dac_in_5: U2.9 (GPIO6); also elsewhere on the board
dac_in_6_msb: U2.10 (GPIO7); also elsewhere on the board
enable_analog_power_supply: U2.12 (GPIO9); also elsewhere on the board
enable_piezo_driver: U2.11 (GPIO8); also elsewhere on the board

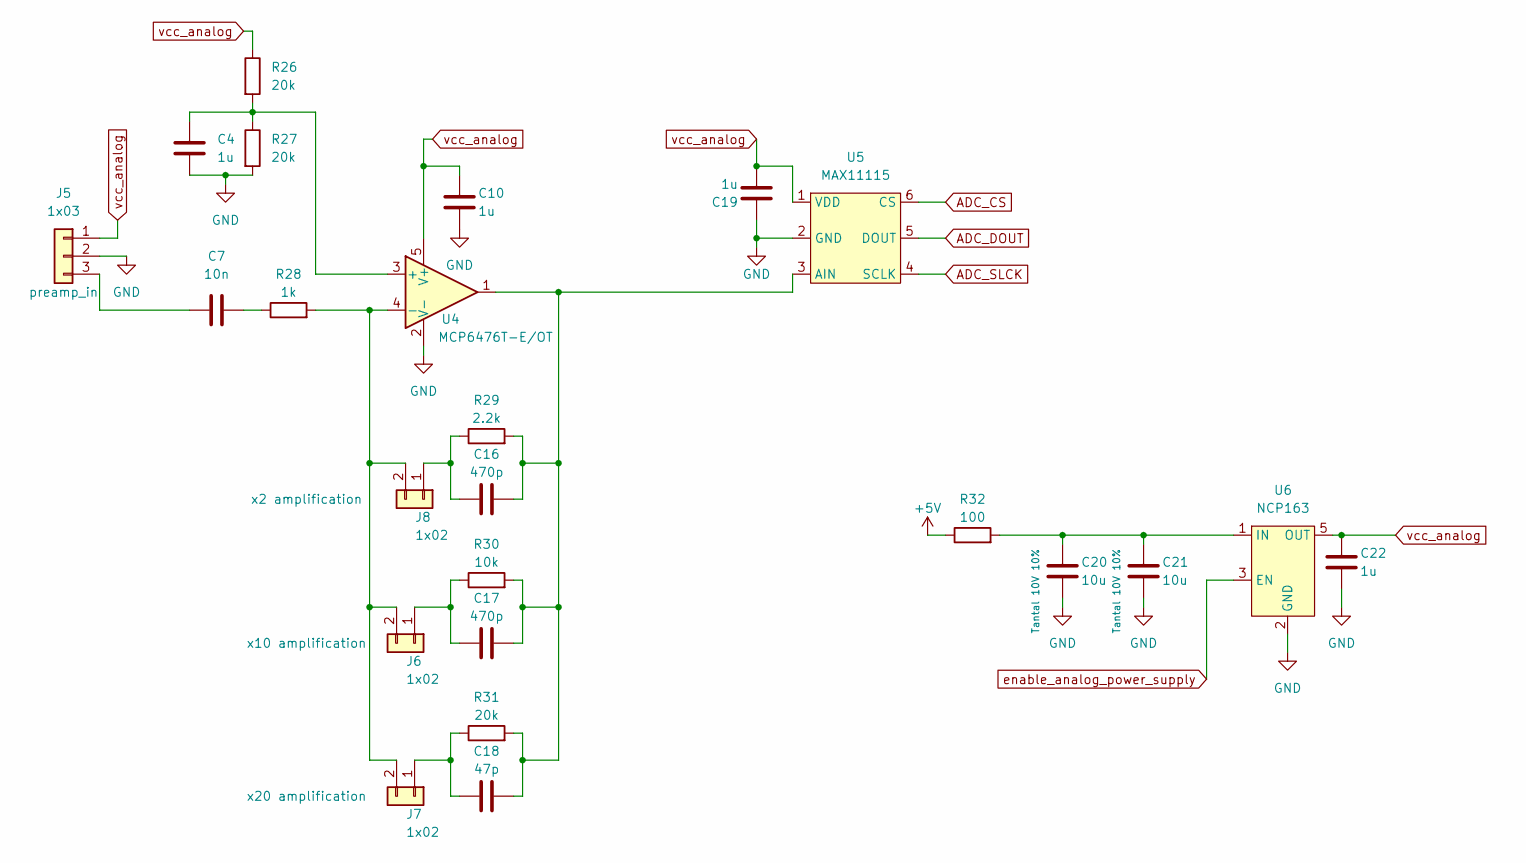
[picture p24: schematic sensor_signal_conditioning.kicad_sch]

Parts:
C4, C10, C19, C22: 1u; C_0805_2012Metric_Pad1.18x1.45mm_HandSolder
C7: 10n; C_0805_2012Metric_Pad1.18x1.45mm_HandSolder
C16, C17: 470p; C_0805_2012Metric_Pad1.18x1.45mm_HandSolder
C18: 47p; C_0805_2012Metric_Pad1.18x1.45mm_HandSolder
C20, C21: 10u; C_1206_3216Metric_Pad1.33x1.80mm_HandSolder
J5: 1x03; PinHeader_1x03_P2.54mm_Vertical
J6, J7, J8: 1x02; PinHeader_1x02_P2.54mm_Vertical
R26, R27, R31: 20k; R_0805_2012Metric_Pad1.20x1.40mm_HandSolder
R28: 1k; R_0805_2012Metric_Pad1.20x1.40mm_HandSolder
R29: 2.2k; R_0805_2012Metric_Pad1.20x1.40mm_HandSolder
R30: 10k; R_0805_2012Metric_Pad1.20x1.40mm_HandSolder
R32: 100; R_0805_2012Metric_Pad1.20x1.40mm_HandSolder
U4: MCP6476T-E/OT; SOT-23-5
U5: MAX11115; SOT-23-6_Handsoldering
U6: NCP163; SOT-23-5_HandSoldering

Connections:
+5V: R32.1; also elsewhere on the board
ADC_CS: U5.6 (CS); also elsewhere on the board
ADC_DOUT: U5.5 (DOUT); also elsewhere on the board
ADC_SLCK: U5.4 (SCLK); also elsewhere on the board
GND: C4.2, C10.2, C19.1, C20.2, C21.2, C22.2, J5.2, R27.2, U4.2 (V-), U5.2 (GND), U6.2 (GND); also elsewhere on the board
unnamed: C4.1, R26.2, R27.1, U4.3 (+)
unnamed: C7.1, J5.3
unnamed: C7.2, R28.1
unnamed: C16.1, J8.1, R29.1
unnamed: C16.2, C17.2, C18.2, R29.2, R30.2, R31.2, U4.1, U5.3 (AIN)
unnamed: C17.1, J6.1, R30.1
unnamed: C18.1, J7.1, R31.1
unnamed: C20.1, C21.1, R32.2, U6.1 (IN)
unnamed: J6.2, J7.2, J8.2, R28.2, U4.4 (-)
enable_analog_power_supply: U6.3 (EN); also elsewhere on the board
vcc_analog: C10.1, C19.2, C22.1, J5.1, R26.1, U4.5 (V+), U5.1 (VDD), U6.5 (OUT)

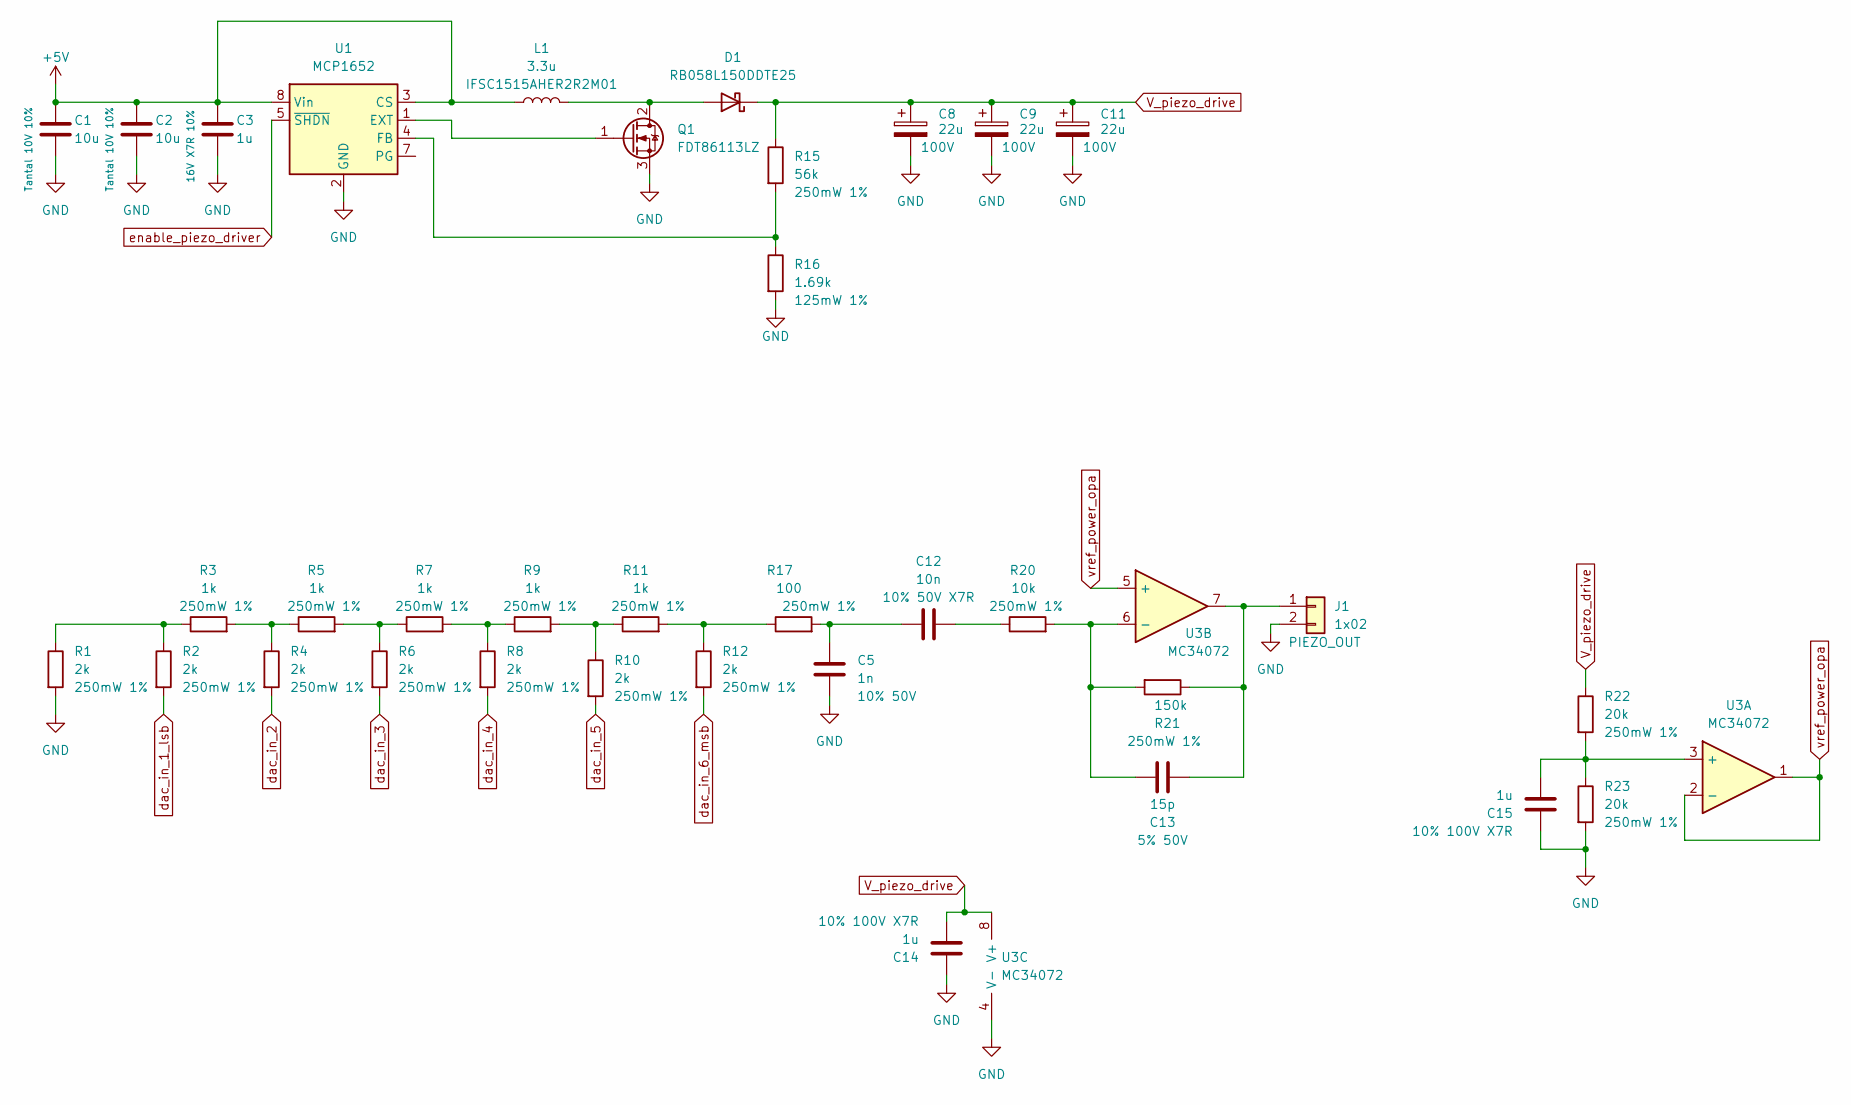
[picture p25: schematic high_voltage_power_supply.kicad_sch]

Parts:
C1, C2: 10u; C_1206_3216Metric_Pad1.33x1.80mm_HandSolder
C3: 1u; C_0805_2012Metric_Pad1.18x1.45mm_HandSolder
C5: 1n; C_0805_2012Metric_Pad1.18x1.45mm_HandSolder
C8, C9, C11: 22u; CP_Elec_8x10.5
C12: 10n; C_0805_2012Metric_Pad1.18x1.45mm_HandSolder
C13: 15p; C_0805_2012Metric_Pad1.18x1.45mm_HandSolder
C14, C15: 1u; C_1206_3216Metric_Pad1.33x1.80mm_HandSolder
D1: RB058L150DDTE25; D_SMA
J1: 1x02; PinHeader_1x02_P2.54mm_Vertical
L1: 3.3u; L_Vishay_IFSC-1515AH_4x4x1.8mm
Q1: FDT86113LZ; SOT-223-3_TabPin2
R1, R2, R4, R6, R8, R10, R12: 2k; R_0805_2012Metric_Pad1.20x1.40mm_HandSolder
R3, R5, R7, R9, R11: 1k; R_0805_2012Metric_Pad1.20x1.40mm_HandSolder
R15: 56k; R_0805_2012Metric_Pad1.20x1.40mm_HandSolder
R16: 1.69k; R_0805_2012Metric_Pad1.20x1.40mm_HandSolder
R17: 100; R_0805_2012Metric_Pad1.20x1.40mm_HandSolder
R20: 10k; R_0805_2012Metric_Pad1.20x1.40mm_HandSolder
R21: 150k; R_0805_2012Metric_Pad1.20x1.40mm_HandSolder
R22, R23: 20k; R_0805_2012Metric_Pad1.20x1.40mm_HandSolder
U1: MCP1652; MSOP-8_3x3mm_P0.65mm
U3: MC34072; SOIC-8_3.9x4.9mm_P1.27mm

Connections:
+5V: C1.1, C2.1, C3.1, L1.1, U1.3 (CS), U1.8 (Vin); also elsewhere on the board
GND: C1.2, C2.2, C3.2, C5.2, C8.2, C9.2, C11.2, C14.1, C15.1, J1.2, Q1.3 (S), R1.2, R16.2, R23.2, U1.2 (GND), U3.4 (V-); also elsewhere on the board
unnamed: C5.1, C12.1, R17.2
unnamed: C12.2, R20.1
unnamed: C13.1, J1.1, R21.1, U3.7
unnamed: C13.2, R20.2, R21.2, U3.6 (-)
unnamed: C15.2, R22.2, R23.1, U3.3 (+)
unnamed: D1.2 (A), L1.2, Q1.2 (D)
unnamed: Q1.1 (G), U1.1 (EXT)
unnamed: R1.1, R2.1, R3.1
unnamed: R3.2, R4.1, R5.1
unnamed: R5.2, R6.1, R7.1
unnamed: R7.2, R8.1, R9.1
unnamed: R9.2, R10.1, R11.1
unnamed: R11.2, R12.1, R17.1
unnamed: R15.2, R16.1, U1.4 (FB)
V_piezo_drive: C8.1, C9.1, C11.1, C14.2, D1.1 (K), R15.1, R22.1, U3.8 (V+)
dac_in_1_lsb: R2.2; also elsewhere on the board
dac_in_2: R4.2; also elsewhere on the board
dac_in_3: R6.2; also elsewhere on the board
dac_in_4: R8.2; also elsewhere on the board
dac_in_5: R10.2; also elsewhere on the board
dac_in_6_msb: R12.2; also elsewhere on the board
enable_piezo_driver: U1.5 (~SHDN); also elsewhere on the board
vref_power_opa: U3.1, U3.2 (-), U3.5 (+)

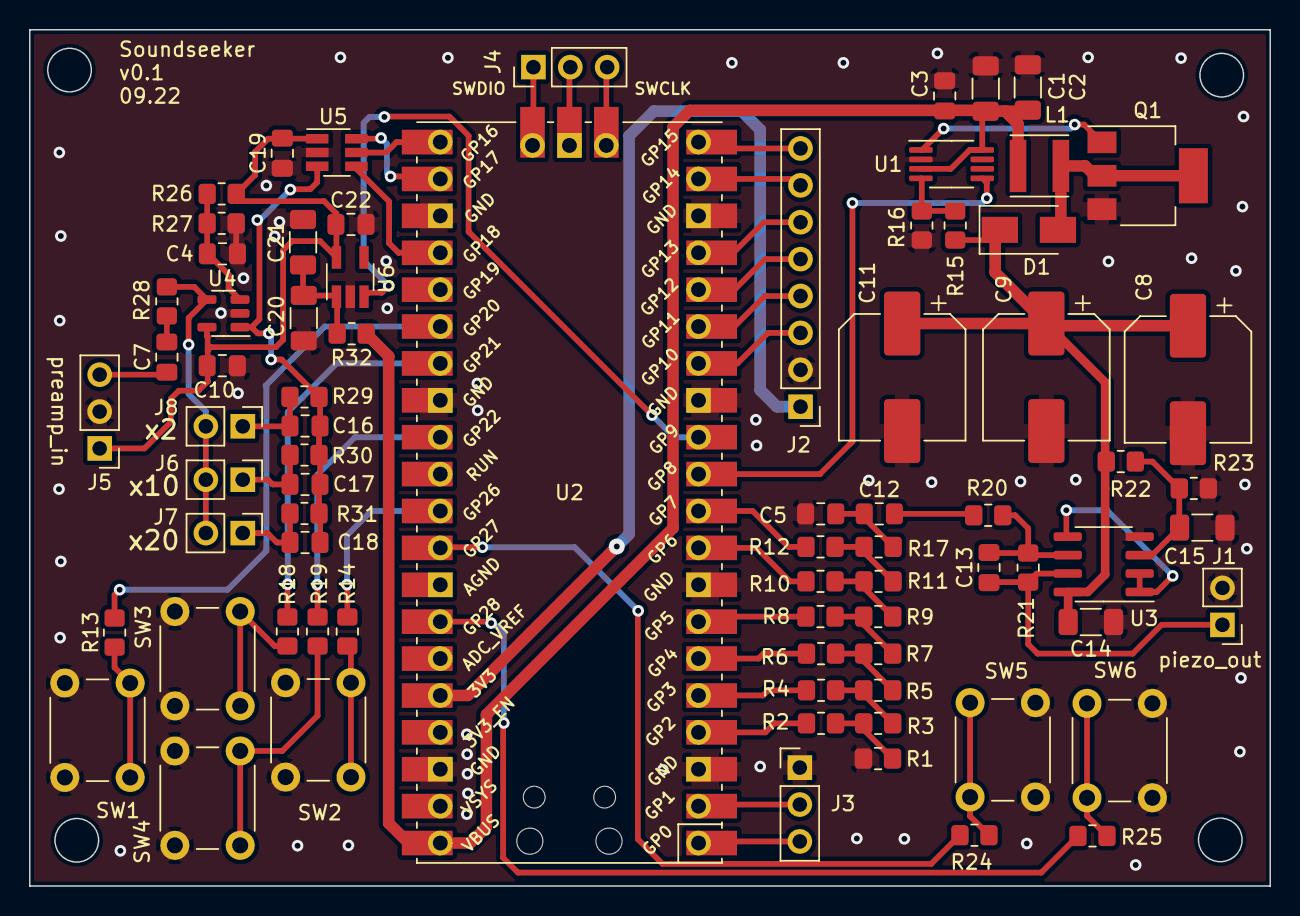
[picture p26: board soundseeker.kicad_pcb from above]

Board: 2 copper layers, 85.4 x 59.0 mm, 76 parts (0 on the bottom side), 63 nets.

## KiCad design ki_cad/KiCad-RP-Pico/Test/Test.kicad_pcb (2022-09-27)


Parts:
J1, J2: Conn_01x20; PinSocket_1x20_P1.00mm_Vertical
J3: Conn_01x03; PinSocket_1x03_P1.00mm_Vertical
U1: Pico; RPi_Pico_SMD_TH

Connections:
GND: J1.3, J1.8, J1.13, J1.18, J2.3, J2.13, J2.18, J3.2, U1.3 (GND), U1.8 (GND), U1.13 (GND), U1.18 (GND), U1.23 (GND), U1.28 (GND), U1.38 (GND), U1.42 (GND)
unnamed: J1.1, U1.1 (GPIO0)
unnamed: J1.2, U1.2 (GPIO1)
unnamed: J1.4, U1.4 (GPIO2)
unnamed: J1.5, U1.5 (GPIO3)
unnamed: J1.6, U1.6 (GPIO4)
unnamed: J1.7, U1.7 (GPIO5)
unnamed: J1.9, U1.9 (GPIO6)
unnamed: J1.10, U1.10 (GPIO7)
unnamed: J1.11, U1.11 (GPIO8)
unnamed: J1.12, U1.12 (GPIO9)
unnamed: J1.14, U1.14 (GPIO10)
unnamed: J1.15, U1.15 (GPIO11)
unnamed: J1.16, U1.16 (GPIO12)
unnamed: J1.17, U1.17 (GPIO13)
unnamed: J1.19, U1.19 (GPIO14)
unnamed: J1.20, U1.20 (GPIO15)
unnamed: J2.1, U1.40 (VBUS)
unnamed: J2.2, U1.39 (VSYS)
unnamed: J2.4, U1.37 (3V3_EN)
unnamed: J2.5, U1.36 (3V3)
unnamed: J2.6, U1.35 (ADC_VREF)
unnamed: J2.7, U1.34 (GPIO28_ADC2)
unnamed: J2.8, U1.33 (AGND)
unnamed: J2.9, U1.32 (GPIO27_ADC1)
unnamed: J2.10, U1.31 (GPIO26_ADC0)
unnamed: J2.11, U1.30 (RUN)
unnamed: J2.12, U1.29 (GPIO22)
unnamed: J2.14, U1.27 (GPIO21)
unnamed: J2.15, U1.26 (GPIO20)
unnamed: J2.16, U1.25 (GPIO19)
unnamed: J2.17, U1.24 (GPIO18)
unnamed: J2.19, U1.22 (GPIO17)
unnamed: J2.20, U1.21 (GPIO16)
unnamed: J3.1, U1.43 (SWDIO)
unnamed: J3.3, U1.41 (SWCLK)


Board: 2 copper layers, 43.0 x 65.0 mm, 4 parts (0 on the bottom side), 36 nets.

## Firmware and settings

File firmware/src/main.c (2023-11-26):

#include "signal_generator/signal_generator.h"
#include "soundseeker.h"
#include "hardware/spi.h"
#include <string.h>

void signal_amplitude_ocillator_demo()
{
  bool up = true;
  float amplitude = 0;
  while (true)
  {
    sleep_ms(100);
    sine_play(amplitude, 40000);

    if (up)
    {
      if (amplitude >= 1)
      {
        amplitude = 1;
        up = false;
      }
      else
      {
        amplitude += 0.05;
      }
    }
    else
    {
      if (amplitude <= 0)
      {
        amplitude = 0;
        up = true;
      }
      else
      {
        amplitude -= 0.05;
      }
    }
  }
}

void signal_freq_ocillator_demo()
{
  bool up = true;
  float freq = 30000;
  while (true)
  {
    sleep_ms(50);
    sine_play(.2, freq);

    if (up)
    {
      if (freq >= 50000)
      {
        freq = 50000;
        up = false;
      }
      else
      {
        freq += 1000;
      }
    }
    else
    {
      if (freq <= 1000)
      {
        freq = 1000;
        up = true;
      }
      else
      {
        freq -= 1000;
      }
    }
  }
}

#define ADC_BUF_LEN 3000
uint16_t adc_buf[ADC_BUF_LEN];
uint dma_rx;
uint dma_tx;
uint timer;
dma_channel_config c;
uint16_t write_val = 0;
void sample_adc()
{
    if (dma_channel_is_busy(dma_rx) || dma_channel_is_busy(dma_tx)) {
        return;
    }

    dma_channel_config c = dma_channel_get_default_config(dma_tx);
    channel_config_set_transfer_data_size(&c, DMA_SIZE_16);
    channel_config_set_dreq(&c, dma_get_timer_dreq(timer));
    channel_config_set_read_increment(&c, false);
    channel_config_set_write_increment(&c, false);
    dma_channel_configure(dma_tx, &c,
                          &spi_get_hw(spi_default)->dr, // write address
                          &write_val, // read address
                          ADC_BUF_LEN, // element count (each element is of size transfer_data_size)
                          false); // don't start yet

  c = dma_channel_get_default_config(dma_rx);
  channel_config_set_transfer_data_size(&c, DMA_SIZE_16);
  channel_config_set_dreq(&c, spi_get_dreq(ADC_SPI, false));
  // do not increment pointer pointing to SPI data register
  channel_config_set_read_increment(&c, false);
  // but update the pointer pointing to the buffer
  channel_config_set_write_increment(&c, true);
  dma_channel_configure(dma_rx, &c,
                        adc_buf,                  // write address
                        &spi_get_hw(ADC_SPI)->dr, // read address
                        ADC_BUF_LEN,              // element count (each element is of size transfer_data_size)
                        false);                   // don't start yet

  // start ADC sampling
  dma_start_channel_mask((1u << dma_rx) | (1u << dma_tx));
}

int main(void)
{
  stdio_init_all();
  sine_generator_init();

  gpio_init(ENABLE_PIEZO_DRIVER_PIN);
  gpio_init(ENABLE_ANALOG_POWER_SUPPLY_PIN);

  gpio_set_dir(ENABLE_PIEZO_DRIVER_PIN, GPIO_OUT);
  gpio_set_dir(ENABLE_ANALOG_POWER_SUPPLY_PIN, GPIO_OUT);

  gpio_put(ENABLE_PIEZO_DRIVER_PIN, 1);
  gpio_put(ENABLE_ANALOG_POWER_SUPPLY_PIN, 1);

  // signal_freq_ocillator_demo();

  uint freq = 40000;
  bool change = true;


  const char* EOL = "ENDE";
  const char* START = "DATA";

  // Enable SPI 0 at 1 MHz and connect to GPIOs
  spi_init(ADC_SPI, 32 * 1000 * 1000);
  spi_set_format(spi_default, 16, SPI_CPOL_1, SPI_CPHA_1, SPI_MSB_FIRST);

  gpio_set_function(ADC_SPI_RX_PIN, GPIO_FUNC_SPI);
  gpio_set_function(ADC_SPI_SCK_PIN, GPIO_FUNC_SPI);
  gpio_set_function(ADC_SPI_CSN_PIN, GPIO_FUNC_SPI);
  // gpio_set_function(ADC_SPI_TX_PIN, GPIO_FUNC_SPI);

  // setup SPI DMA
  dma_rx = dma_claim_unused_channel(true);
  dma_tx = dma_claim_unused_channel(true);


  uint timer = dma_claim_unused_timer(true);
  dma_timer_set_fraction(timer, 1, 125);
  // We set the inbound DMA to transfer from the SPI receive FIFO to a memory buffer paced by the SPI RX FIFO DREQ
  // We configure the read address to remain unchanged for each element, but the write
  // address to increment (so data is written throughout the buffer)

  
    //sine_play_pulses(1, freq, 3);
    //sine_play_pulses(1, freq, 3);
    //sine_play(1, freq);
  while(true) {
    sine_play_pulses(.7, freq, 3);
    sample_adc();
    sleep_ms(300);
    uint16_t *wordPtr = adc_buf;
    uint8_t *bytePtr = (uint8_t *)adc_buf;
    for (uint i = 0; i < ADC_BUF_LEN; i++)
    {
      // shift 7 bits because of ADC data format (see data sheet for MAX1115 ADC)
      //if((*wordPtr >> 7) < 10) {
      //  printf("oh oh :(\n");
      //}
      *bytePtr = (uint8_t)(*wordPtr >> 7);
      bytePtr++;
      wordPtr++;
    }
    printf(START);
    uart_write_blocking (uart0, (uint8_t*)&adc_buf[0], ADC_BUF_LEN);
    printf(EOL);
  }

  while (1)
    tight_loop_contents();
}

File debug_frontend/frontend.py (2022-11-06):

import matplotlib.pyplot as plt
import numpy as np
import serial_data_fetch
from multiprocessing import Process, Pipe


# pyserial needed
# installation: pip3 install pyserial


def ui_thread(pipe):
    x = [0,1,2,3,4,5,6,7,8,9]
    y = np.zeros([10])
    
    plt.ion()
    fig = plt.figure()
    ax = fig.add_subplot(1, 1, 1)
    line1, = ax.plot(x, y, color='tab:blue')


    # set the limits
    ax.set_xlim([0, 9])
    ax.set_ylim([0,255])
    ax.set_title('line plot with data points')

    
    while True:
        data = pipe.recv()
        print("got deta :)")
        ax.set_xlim([0, len(data)])
        line1.set_xdata(np.arange(len(data)))
        line1.set_ydata(data)
        fig.canvas.draw()
        fig.canvas.flush_events()


if __name__ == '__main__':
    parent_conn, child_conn = Pipe()
    p = Process(target=serial_data_fetch.serial_data_parser, args=(child_conn,))
    p.start()
    ui_thread(parent_conn)

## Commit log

2021-06-20 add pics for first prototype
2022-09-13 add kicad
    [high_voltage_power_supply.kicad_sch, piezo_driver.kicad_sch, soundseeker.kicad_pcb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]
2022-09-14 first working pwm sine generator
2022-09-15 clean pwm code
2022-09-15 add first attempt of parallel r2r-ladder driver
2022-09-27 add preamp schematic
    [Pico.skp, Test.kicad_pcb, Test.kicad_sch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]
2022-10-01 add buttons and display spi connections
    [high_voltage_power_supply.kicad_sch, sensor_signal_conditioning.kicad_sch, soundseeker.kicad_sch]
2022-10-02 sounseeker base board (evaluartion) PCB layout
    [high_voltage_power_supply.kicad_sch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]
2022-10-03 finish base board (evaluation)
    [high_voltage_power_supply.kicad_sch, sensor_signal_conditioning.kicad_sch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]
2022-11-02 first working hardware board :)
    [high_voltage_power_supply.kicad_sch, piezo_sensor_amplifier.kicad_pcb, soundseeker.kicad_pcb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]
2022-11-04 first working demo of SPI ADC sampling
